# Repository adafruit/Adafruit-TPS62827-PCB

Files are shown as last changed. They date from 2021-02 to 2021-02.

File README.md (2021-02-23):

## TPS62827 3.3V Buck Converter Breakout PCB

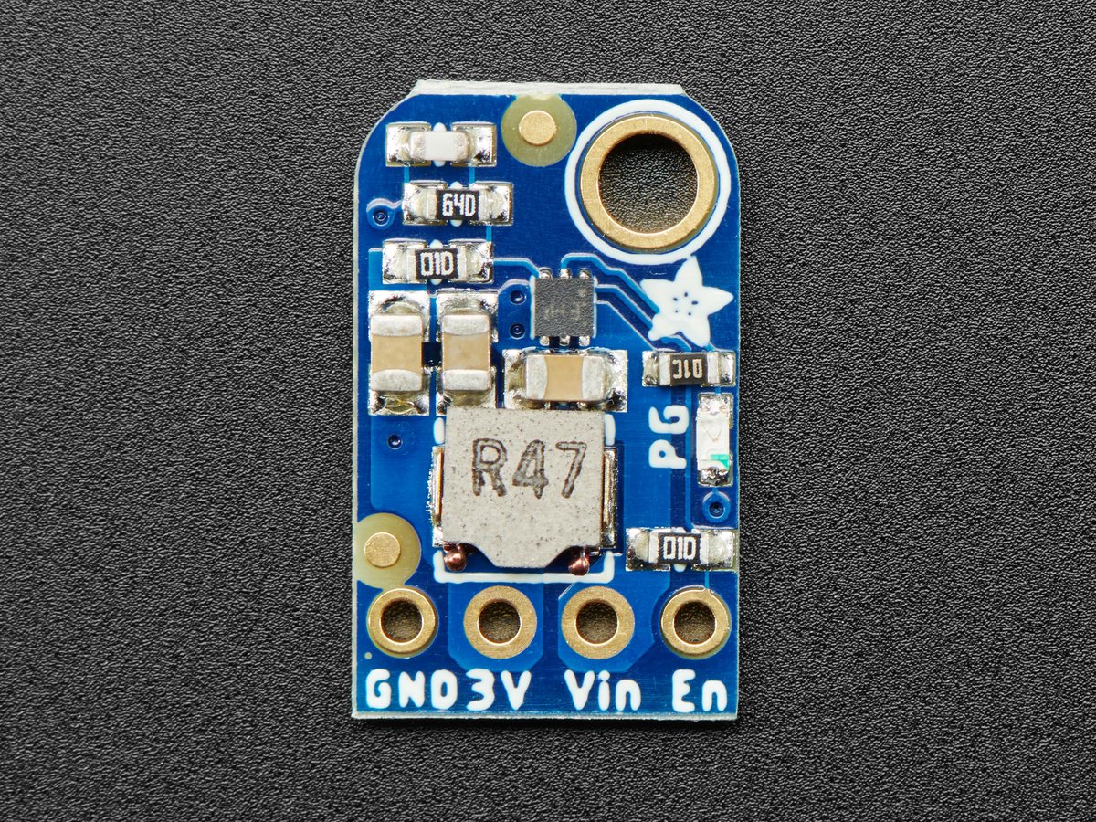
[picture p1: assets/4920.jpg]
<a href="http://www.adafruit.com/products/4920"><br/>
Click here to purchase one from the Adafruit shop</a>

PCB files for the TPS62827 3.3V Buck Converter Breakout. 

Format is EagleCAD schematic and board layout
* https://www.adafruit.com/product/4920

### Description

This little buck converter based on the TPS62827 is super handy, taking up to 5.5V input and providing a 3.3V output with up to 2A current. It's great for supplying power to hungry 3.3V voltage circuits from a range of battery or power options.  This chip provides up to 2 Amp load current across the entire input voltage range of 3.4 to 5.5V. It's not a huge range but does cover LiPoly batteries, 3 alkalines, and USB power.

Great for your portable project, we made this "pin compatible" with the LM1117-3.3V TO-220 chip so you can swap it in for better performance (90-95% efficiency!) There's also an ENable pin, tie it low to shut down the output completely.

The Adafruit TPS62827 Breakout runs at 2.2-MHz fixed-frequency. Even though the chip itself supports up to 4A, we found that 2 Amps or so was a good max to stick to for constant current draw and 3 Amps for temporary peak current draws. We did use a 2 oz copper double-layer PCB.

If you need a wider input range, check out the 3.3V output MPM3610 breakout with up to 20V input!

Comes with a fully assembled and tested breakout board.  We also include header to plug it into a breadboard.

### License

Adafruit invests time and resources providing this open source design, please support Adafruit and open-source hardware by purchasing products from [Adafruit](https://www.adafruit.com)!

Designed by Limor Fried/Ladyada for Adafruit Industries.

Creative Commons Attribution/Share-Alike, all text above must be included in any redistribution. 
See license.txt for additional details.

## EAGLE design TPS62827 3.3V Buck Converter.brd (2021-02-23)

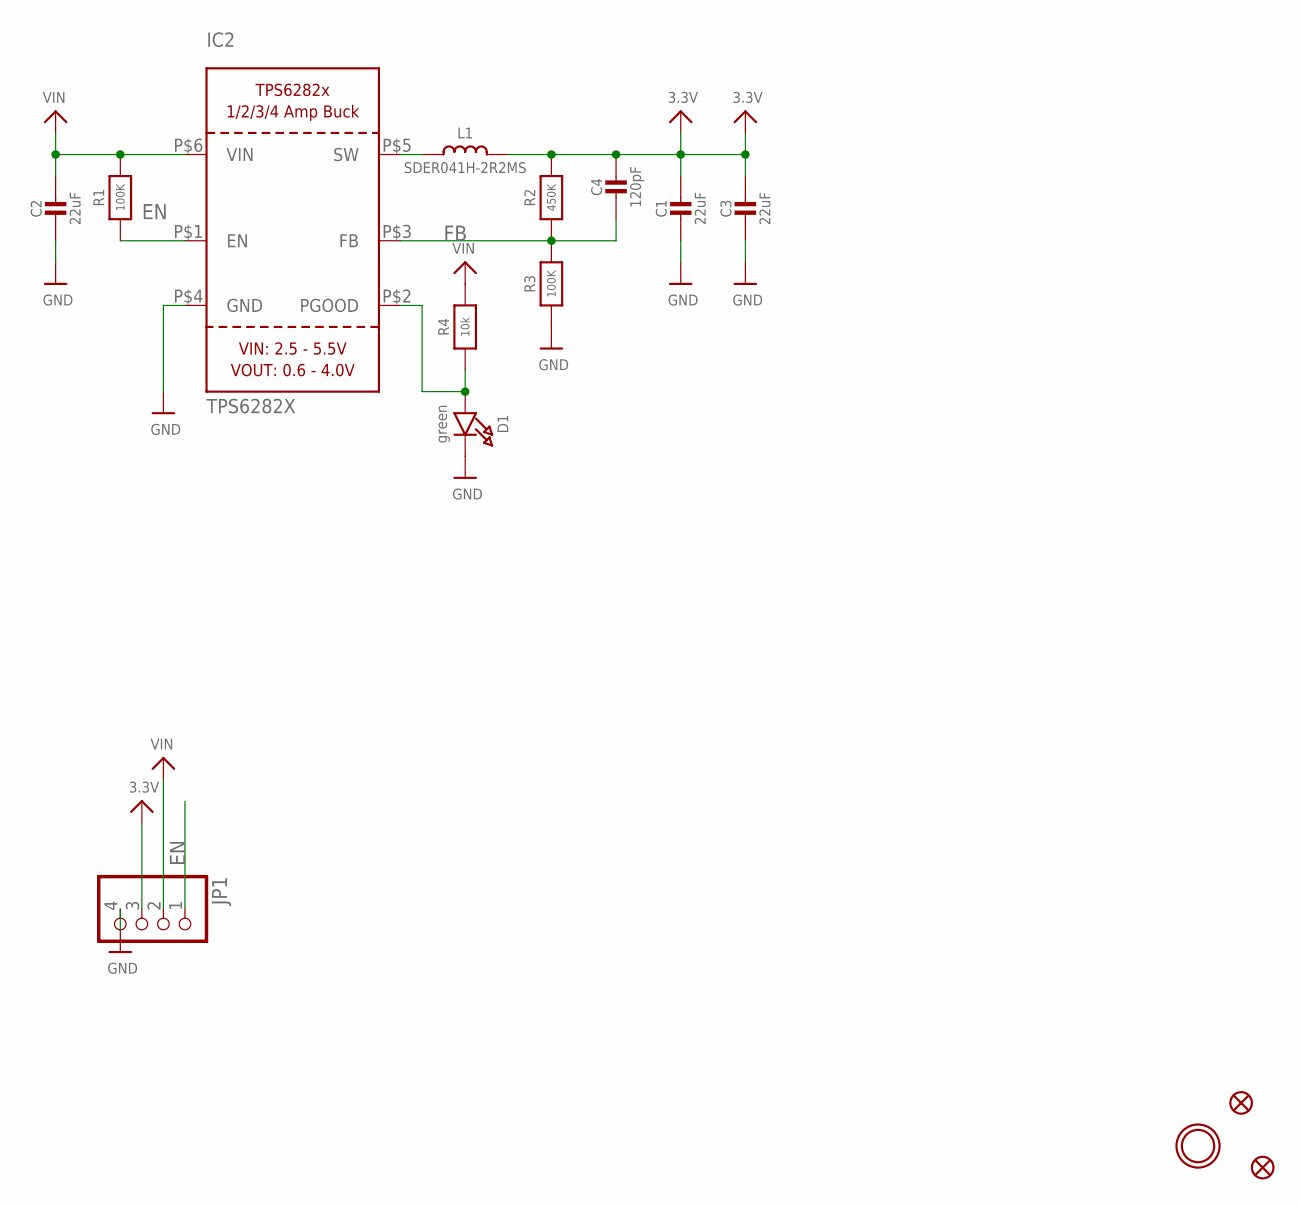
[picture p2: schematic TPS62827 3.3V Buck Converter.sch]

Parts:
C1, C2, C3: 22uF; 0805-NO
C4: 120pF; 0603-NO
D1: green; CHIPLED_0603_NOOUTLINE
FID1, FID2: FIDUCIAL_1MM
IC2: TPS6282X; VSON_6
JP1: HEADER-1X4ROUND; 1X04_ROUND
L1: SDER041H-2R2MS; INDUCTOR_4X4MM_SRP0415
R1, R3: 100K; 0603-NO
R2: 450K; 0603-NO
R4: 10k; _0603MP
U$9: MOUNTINGHOLE2.5; MOUNTINGHOLE_2.5_PLATED

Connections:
3.3V: C1.1, C3.1, C4.1, JP1.3, L1.P$2 (2), R2.2
EN: IC2.P$1 (EN), JP1.1, R1.2
FB: C4.2, IC2.P$3 (FB), R2.1, R3.2
GND: C1.2, C2.2, C3.2, D1.C, IC2.P$4 (GND), JP1.4, R3.1
unnamed: IC2.P$5 (SW), L1.P$1 (1)
unnamed: D1.A, IC2.P$2 (PGOOD), R4.1
VIN: C2.1, IC2.P$6 (VIN), JP1.2, R1.1, R4.2

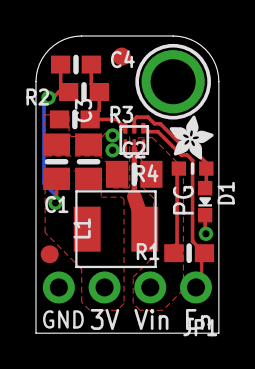
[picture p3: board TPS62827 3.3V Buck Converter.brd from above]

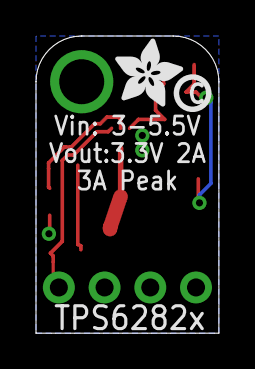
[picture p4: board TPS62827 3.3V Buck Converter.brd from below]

Board: 2 copper layers, 10.2 x 16.5 mm, 18 parts (2 on the bottom side), 7 nets.

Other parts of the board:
U$10: PCBFEAT-REV-040
U$11: ADAFRUIT_2.5MM
U$18: ADAFRUIT_3.5MM

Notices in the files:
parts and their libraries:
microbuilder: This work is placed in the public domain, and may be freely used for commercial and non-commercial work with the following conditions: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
